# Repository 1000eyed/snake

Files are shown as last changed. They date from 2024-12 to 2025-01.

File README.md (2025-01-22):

# Snake

A semi-ortholinear keyboard with LEDs, rotary encoder support and spacebar options.

## How to build one

Very easy project.

### Part list
| # | name | comments |
|---|---|---|
| 1 | main PCB | Order at fabricator of your choice (ouch, expensive!) |
| 42 | hotswap sockets | Whatever you are into |
| 42 | switches | MX compatible |
| 42 | Keycaps | MX-compatible |
| 1 | Rotary Encoder | optional |
| NA | Rubber cord D3.53 mm |  https://www.amazon.de/-/en/SHOCRE-Rubber-Gasket-Nitrile-Diameter/dp/B0CGDMGRZM |

- Solder the sockets to the PCB according to chosen layout. 
- Mount stabilizers. Note: depending on the layout you [i]may[/i] need to file just a tad the stabilizer lips, so they clear the diodes. If they do not seem to fit, do not force them into place, inspect and file if needed!
- Mount the plate to the PCB and secure it with switches in the corners. 
- Mount all other switches.
- Cut and insert cord pieces into the pockets between the PCB and the plate.
- Insert the assembly into the case. Start with the USB side.

### Firmware

- Install WinUSB driver, using Zadig (https://github.com/qmk/qmk_firmware/blob/master/docs/driver_installation_zadig.md)
- Flash the firmware onto the board. Bootloader mode: hold top left key while plugging in. I used QMK Toolbox (https://qmk.fm/toolbox).

### Done

Enjoy your Snake!

## Acknowledgements

Joe Scotto for publishing the STM32 Scottomodule (https://www.youtube.com/joe_scotto). 
Theycallmeboxy for case inspirations (https://github.com/theycallmeboxy/bassik).

## Gallery



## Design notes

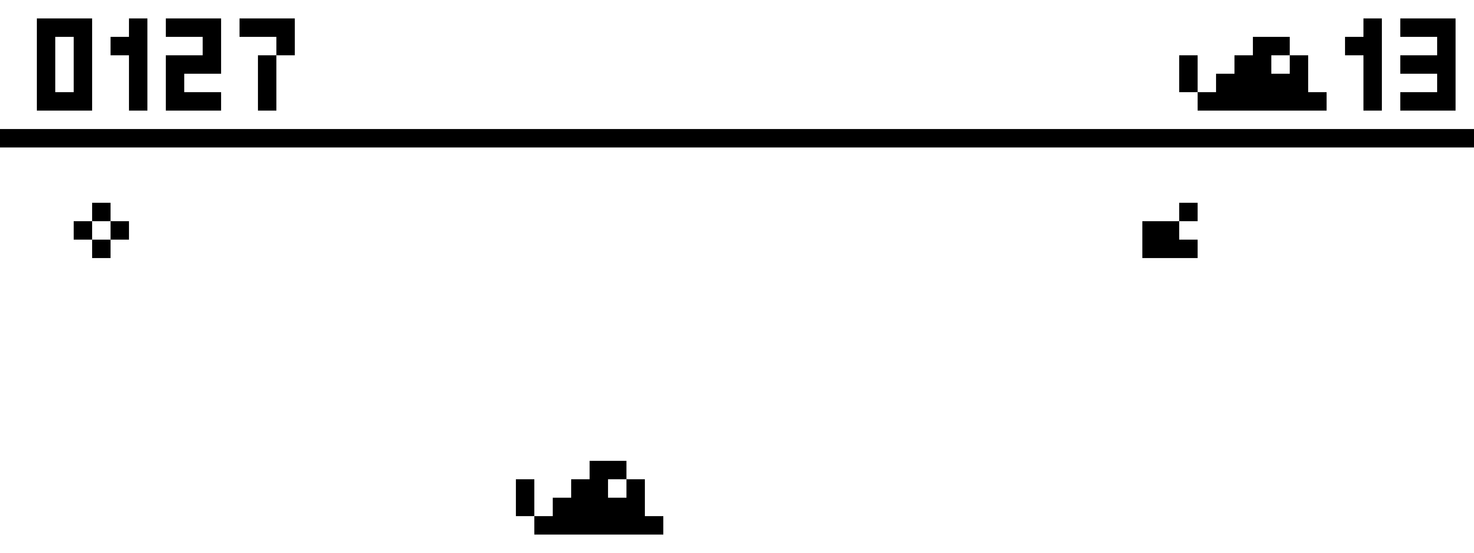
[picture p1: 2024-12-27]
snake-pcb/snake.png

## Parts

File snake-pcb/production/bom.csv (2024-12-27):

Designator | Footprint | Quantity | Value | LCSC Part #
C10, C11, C13, C16, C7, CAPLED1, CAPLED10, CAPLED11, CAPLED12, CAPLED13, CAPLED14, CAPLED15, CAPLED16, CAPLED17, CAPLED18, CAPLED19, CAPLED2, CAPLED20, CAPLED21, CAPLED22, CAPLED23, CAPLED24, CAPLED25, CAPLED26, CAPLED27, CAPLED28, CAPLED29, CAPLED3, CAPLED30, CAPLED31, CAPLED32, CAPLED33, CAPLED34, CAPLED35, CAPLED36, CAPLED37, CAPLED38, CAPLED39, CAPLED4, CAPLED40, CAPLED41, CAPLED42, CAPLED43, CAPLED5, CAPLED6, CAPLED7, CAPLED8, CAPLED9 | Capacitor_0402 | 48 | 100nF | C307331
C12, C17 | Capacitor_0402 | 2 | 4.7uF | C23733
C14 | Capacitor_0402 | 1 | 10nF | C15195
C15, C8, C9 | Capacitor_0402 | 3 | 1uF | C52923
D1, D10, D11, D12, D13, D14, D15, D16, D17, D18, D19, D2, D20, D21, D22, D23, D24, D25, D26, D27, D28, D29, D3, D30, D31, D32, D33, D34, D35, D36, D37, D38, D39, D4, D40, D41, D42, D5, D6, D7, D8, D9, DLED1 | D_SOD-123 | 43 | 1N4148W
F1 | Fuse_0603 | 1 | 500mA | C210357
J1 | USB_C_HRO_TYPE-C-31-M-12 | 1 | USB_C | C165948
J2 | JST_EH_B5B-EH-A_1x05_P2.50mm_Vertical | 1 | Conn_01x05_Socket
LED1, LED10, LED11, LED12, LED13, LED14, LED15, LED16, LED17, LED18, LED19, LED2, LED20, LED21, LED22, LED23, LED24, LED25, LED26, LED27, LED28, LED29, LED3, LED30, LED31, LED32, LED33, LED34, LED35, LED36, LED37, LED38, LED39, LED4, LED40, LED41, LED42, LED43, LED5, LED6, LED7, LED8, LED9 | LED_SK6812MINI | 43 | SK6812MINI
MX1, MX10, MX11, MX12, MX13, MX14, MX15, MX16, MX17, MX18, MX19, MX2, MX20, MX21, MX22, MX23, MX24, MX25, MX26, MX27, MX28, MX29, MX3, MX30, MX31, MX32, MX33, MX34, MX35, MX37, MX38, MX39, MX4, MX40, MX41, MX42, MX43, MX5, MX6, MX7, MX8, MX9 | SW_MX_HS_CPG151101S11_1u | 42 | MX_SW_solder
MX36 | SW_MX_HS_CPG151101S11_1.25u | 1 | MX_SW_solder
R1 | Resistor_0402 | 1 | 10k | C25744
R2, R3 | Resistor_0402 | 2 | 5.1k | C25905
S35 | STAB_MX_P_ISO-ROT | 1 | MX_stab
S39 | STAB_MX_P_2.75u | 1 | MX_stab
S40 | STAB_MX_P_2.25u | 1 | MX_stab
SW1 | Button_TL3342 | 1 | SW_Push | C115351
SW2 | Encoder_EC11_MX | 1 | RotaryEncoder_Switch
U1 | Package_LQFP-48_7x7mm_P0.5 | 1 | STM32F072CBT6 | C81720
U3 | Voltage_SOT-23 | 1 | XC6206 | C5446
U4 | ESD_SOT-23-6 | 1 | USBLC6-2SC6 | C2827654

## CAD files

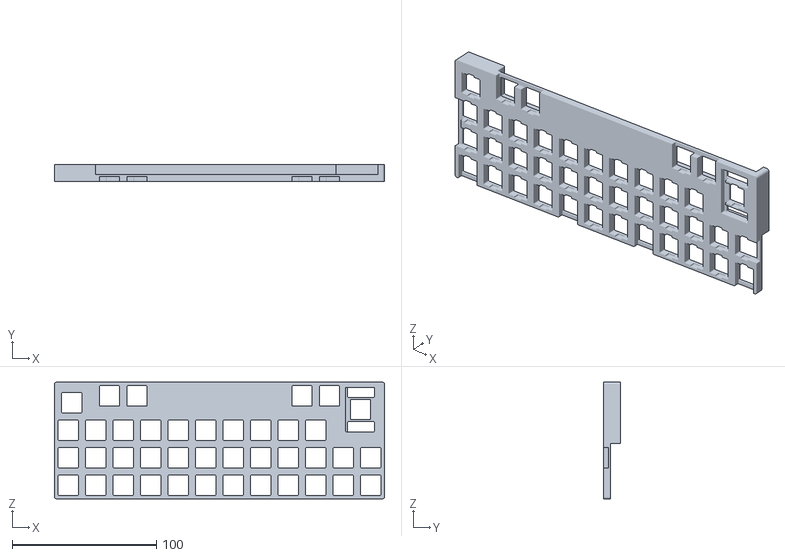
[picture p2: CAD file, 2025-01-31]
snake-case/plate, ortho+ISO+7U seesaw mount.stl
228.6 x 12.0 x 81.0

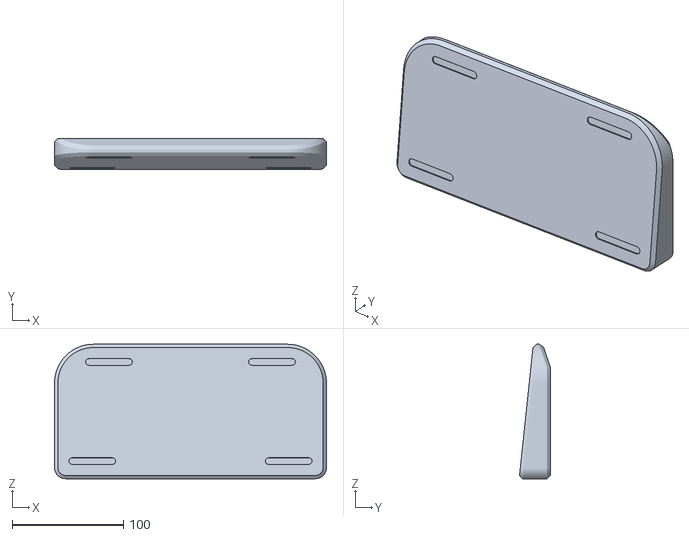
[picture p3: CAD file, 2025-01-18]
snake-case/case deeper SKUF.stl
244.6 x 27.9 x 121.0

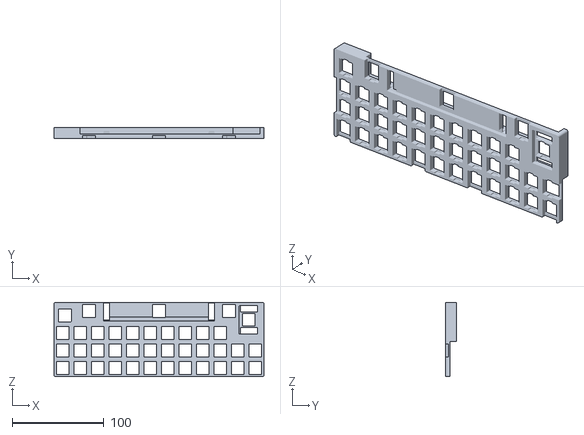
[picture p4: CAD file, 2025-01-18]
snake-case/plate, ortho+ISO+7U stabilized.stl
228.6 x 12.0 x 81.0

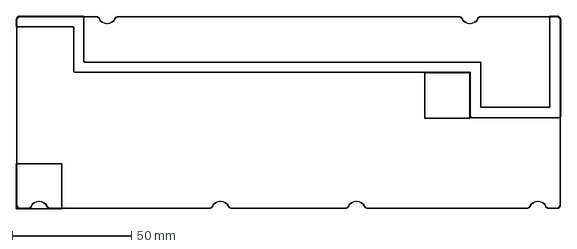
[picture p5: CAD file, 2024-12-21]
snake-case/pcb edge cuts and led position.dxf
228.6 x 81.0 mm

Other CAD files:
snake-case/snake v9.step
snake-case/case.stl
snake-case/snake.f3d

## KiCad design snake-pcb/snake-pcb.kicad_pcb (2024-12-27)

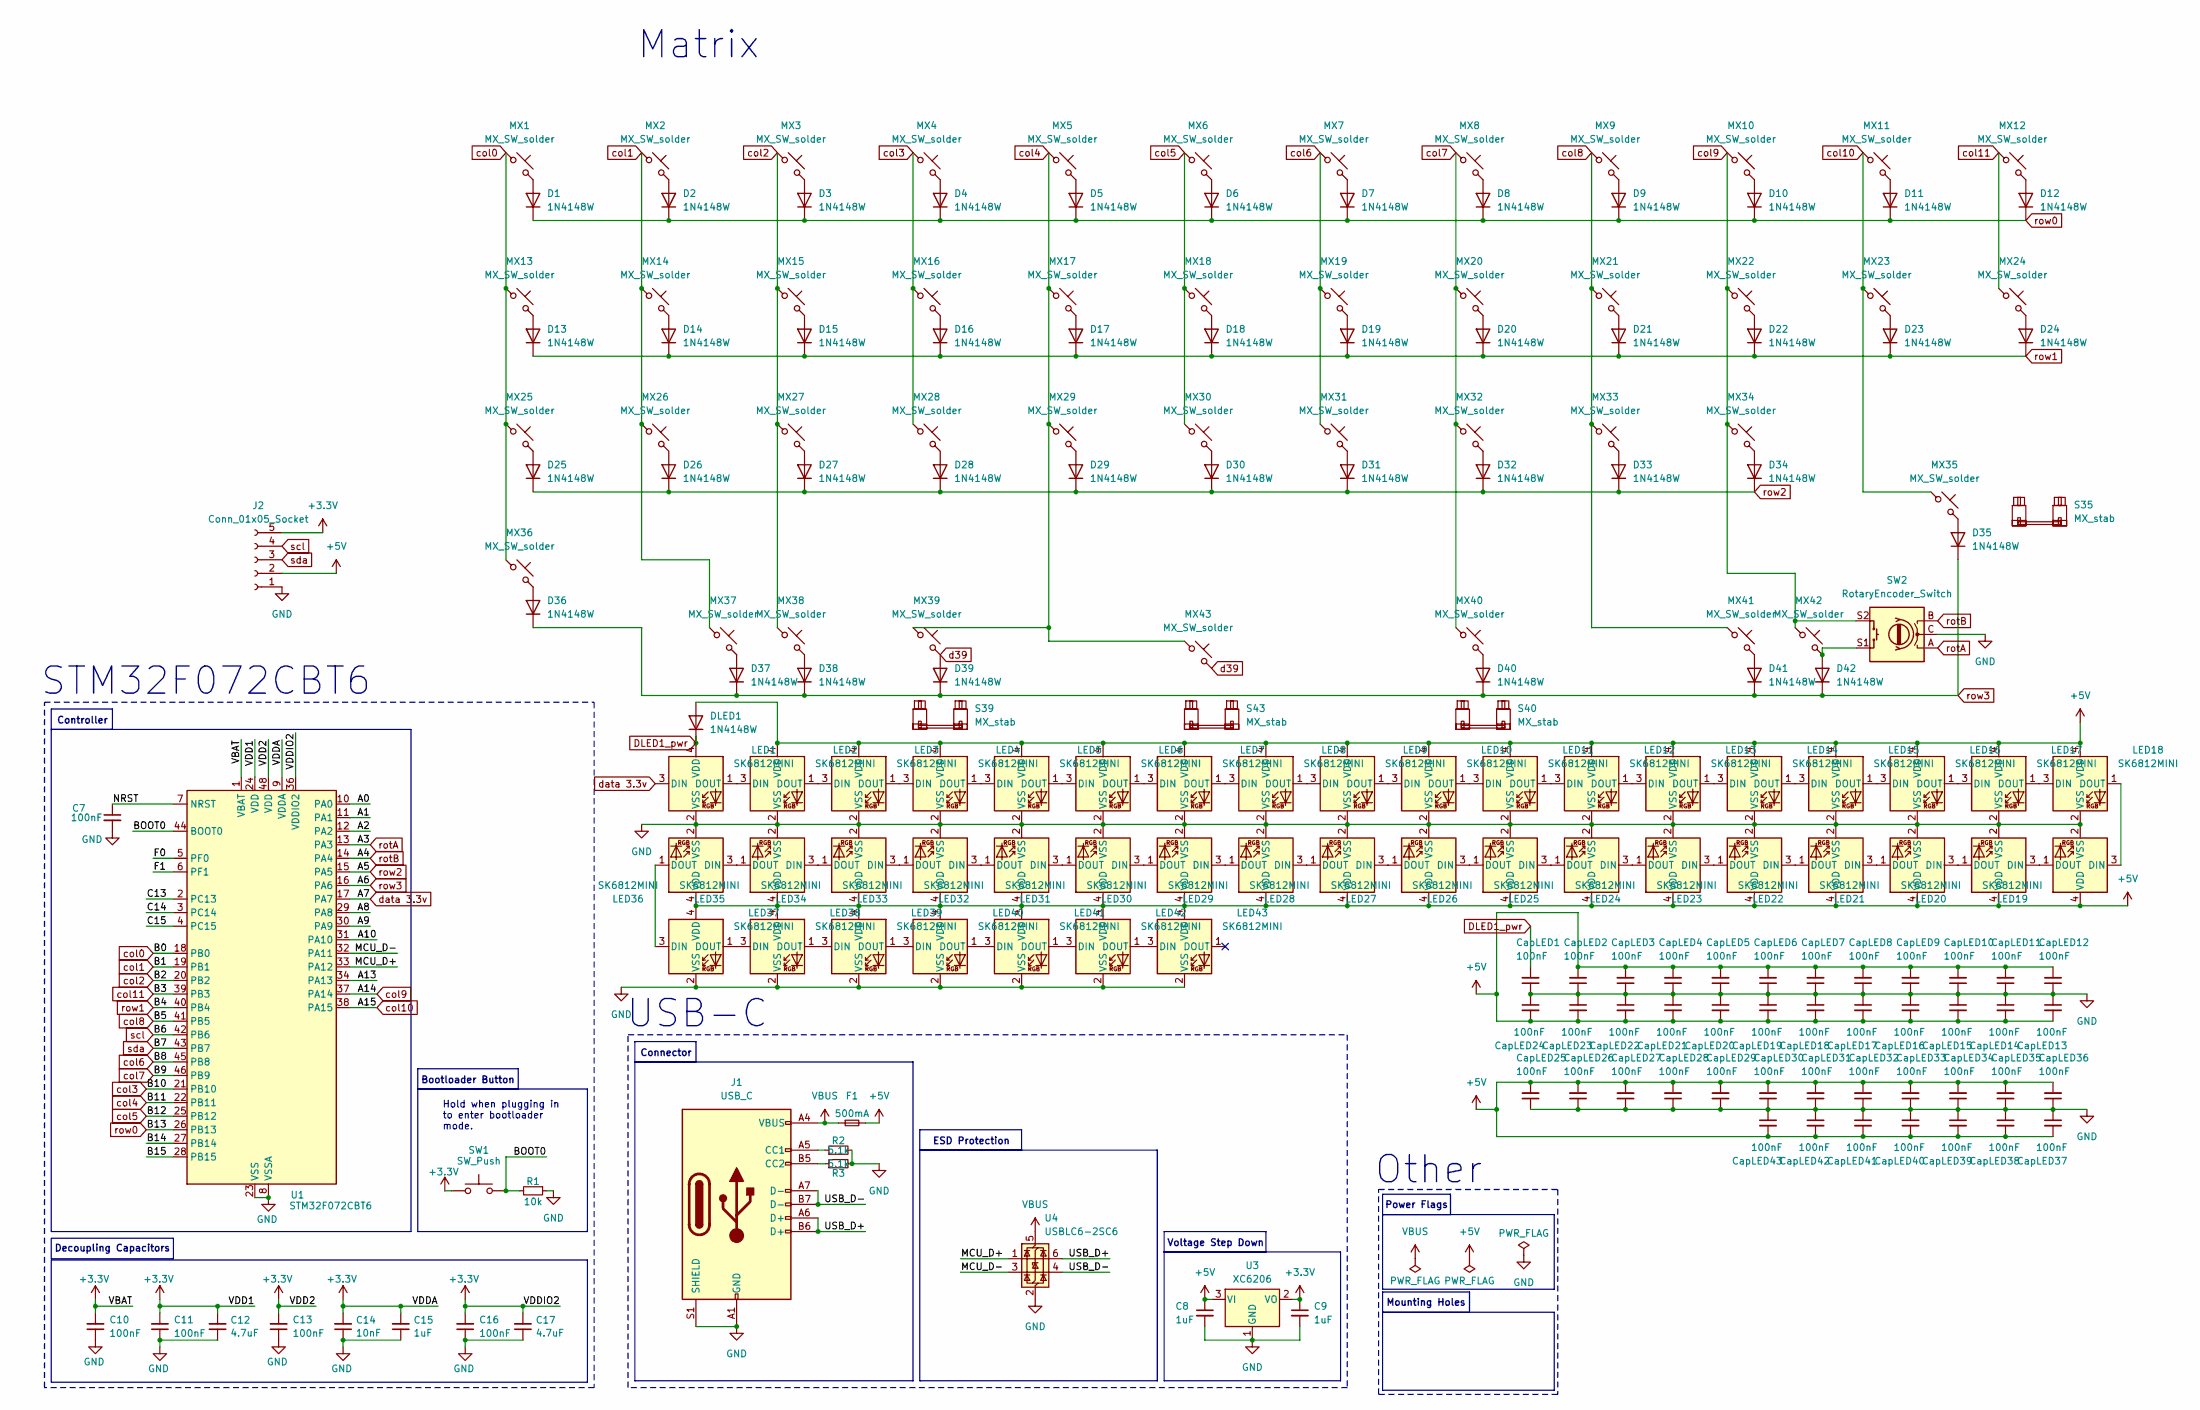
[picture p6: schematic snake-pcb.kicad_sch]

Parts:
C7: 100nF; Capacitor_0402; LCSC C307331
C8, C9: 1uF; Capacitor_0402; LCSC C52923
C10, C11, C13, C16: 100nF; Capacitor_0402; MPN CL05B104KB54PNC; LCSC C307331
C12, C17: 4.7uF; Capacitor_0402; MPN CL05A475MP5NRNC; LCSC C23733
C14: 10nF; Capacitor_0402; MPN CL05B103KB5NNNC; LCSC C15195
C15: 1uF; Capacitor_0402; MPN CL05A105KA5NQNC; LCSC C52923
CapLED1, CapLED2, CapLED3, CapLED4, CapLED5, CapLED6, CapLED7, CapLED8, CapLED9, CapLED10, CapLED11, CapLED12, CapLED13, CapLED14, CapLED15, CapLED16, CapLED17, CapLED18, CapLED19, CapLED20, CapLED21, CapLED22, CapLED23, CapLED24, CapLED25, CapLED26, CapLED27, CapLED28, CapLED29, CapLED30, CapLED31, CapLED32, CapLED33, CapLED34, CapLED35, CapLED36, CapLED37, CapLED38, CapLED39, CapLED40, CapLED41, CapLED42, CapLED43: 100nF; Capacitor_0402; MPN CL05B104KB54PNC; LCSC C307331
D1, D2, D3, D4, D5, D6, D7, D8, D9, D10, D11, D12, D13, D14, D15, D16, D17, D18, D19, D20, D21, D22, D23, D24, D25, D26, D27, D28, D29, D30, D31, D32, D33, D34, D35, D36, D37, D38, D39, D40, D41, D42: 1N4148W; D_SOD-123
DLED1: 1N4148W; D_SOD-123
F1: 500mA; Fuse_0603; LCSC C210357
J1: USB_C; USB_C_HRO_TYPE-C-31-M-12; LCSC C165948
J2: Conn_01x05_Socket; JST_EH_B5B-EH-A_1x05_P2.50mm_Vertical
LED1, LED2, LED3, LED4, LED5, LED6, LED7, LED8, LED9, LED10, LED11, LED12, LED13, LED14, LED15, LED16, LED17, LED18, LED19, LED20, LED21, LED22, LED23, LED24, LED25, LED26, LED27, LED28, LED29, LED30, LED31, LED32, LED33, LED34, LED35, LED36, LED37, LED38, LED39, LED40, LED41, LED42, LED43: SK6812MINI; LED_SK6812MINI
MX1, MX2, MX3, MX4, MX5, MX6, MX7, MX8, MX9, MX10, MX11, MX12, MX13, MX14, MX15, MX16, MX17, MX18, MX19, MX20, MX21, MX22, MX23, MX24, MX25, MX26, MX27, MX28, MX29, MX30, MX31, MX32, MX33, MX34, MX35, MX37, MX38, MX39, MX40, MX41, MX42, MX43: MX_SW_solder; SW_MX_HS_CPG151101S11_1u
MX36: MX_SW_solder; SW_MX_HS_CPG151101S11_1.25u
R1: 10k; Resistor_0402; LCSC C25744
R2, R3: 5.1k; Resistor_0402; LCSC C25905
S35: MX_stab; STAB_MX_P_ISO-ROT
S39: MX_stab; STAB_MX_P_2.75u
S40: MX_stab; STAB_MX_P_2.25u
S43: MX_stab; STAB_MX_P_7u
SW1: SW_Push; Button_TL3342; LCSC C115351
SW2: RotaryEncoder_Switch; Encoder_EC11_MX
U1: STM32F072CBT6; Package_LQFP-48_7x7mm_P0.5; LCSC C81720
U3: XC6206; Voltage_SOT-23; LCSC C5446
U4: USBLC6-2SC6; ESD_SOT-23-6; LCSC C2827654

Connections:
+3.3V: C9.1, C10.2, C11.2, C12.2, C13.2, C14.2, C15.2, C16.2, C17.2, J2.5, SW1.1, U1.1 (VBAT), U1.9 (VDDA), U1.24 (VDD), U1.36 (VDDIO2), U1.48 (VDD), U3.2 (VO)
+5V: C8.1, CapLED2.2, CapLED3.2, CapLED4.2, CapLED5.2, CapLED6.2, CapLED7.2, CapLED8.2, CapLED9.2, CapLED10.2, CapLED11.2, CapLED12.2, CapLED13.2, CapLED14.2, CapLED15.2, CapLED16.2, CapLED17.2, CapLED18.2, CapLED19.2, CapLED20.2, CapLED21.2, CapLED22.2, CapLED23.2, CapLED24.2, CapLED25.2, CapLED26.2, CapLED27.2, CapLED28.2, CapLED29.2, CapLED30.2, CapLED31.2, CapLED32.2, CapLED33.2, CapLED34.2, CapLED35.2, CapLED36.2, CapLED37.2, CapLED38.2, CapLED39.2, CapLED40.2, CapLED41.2, CapLED42.2, CapLED43.2, DLED1.2 (A), F1.2, J2.2, LED2.4 (VDD), LED3.4 (VDD), LED4.4 (VDD), LED5.4 (VDD), LED6.4 (VDD), LED7.4 (VDD), LED8.4 (VDD), LED9.4 (VDD), LED10.4 (VDD), LED11.4 (VDD), LED12.4 (VDD), LED13.4 (VDD), LED14.4 (VDD), LED15.4 (VDD), LED16.4 (VDD), LED17.4 (VDD), LED18.4 (VDD), LED19.4 (VDD), LED20.4 (VDD), LED21.4 (VDD), LED22.4 (VDD), LED23.4 (VDD), LED24.4 (VDD), LED25.4 (VDD), LED26.4 (VDD), LED27.4 (VDD), LED28.4 (VDD), LED29.4 (VDD), LED30.4 (VDD), LED31.4 (VDD), LED32.4 (VDD), LED33.4 (VDD), LED34.4 (VDD), LED35.4 (VDD), LED36.4 (VDD), LED37.4 (VDD), LED38.4 (VDD), LED39.4 (VDD), LED40.4 (VDD), LED41.4 (VDD), LED42.4 (VDD), LED43.4 (VDD), U3.3 (VI)
/A0: U1.10 (PA0)
/A1: U1.11 (PA1)
/A2: U1.12 (PA2)
/A8: U1.29 (PA8)
/A9: U1.30 (PA9)
/A10: U1.31 (PA10)
/A13: U1.34 (PA13)
/B14: U1.27 (PB14)
/B15: U1.28 (PB15)
/BOOT0: R1.2, SW1.2, U1.44 (BOOT0)
/C13: U1.2 (PC13)
/C14: U1.3 (PC14)
/C15: U1.4 (PC15)
/F0: U1.5 (PF0)
/F1: U1.6 (PF1)
/MCU_D+: U1.33 (PA12), U4.1 (I/O1)
/MCU_D-: U1.32 (PA11), U4.3 (I/O2)
/NRST: C7.1, U1.7 (NRST)
/USB_D+: J1.A6 (D+), J1.B6 (D+), U4.6 (I/O1)
/USB_D-: J1.A7 (D-), J1.B7 (D-), U4.4 (I/O2)
DLED1_pwr: CapLED1.2, DLED1.1 (K), LED1.4 (VDD)
GND: C7.2, C8.2, C9.2, C10.1, C11.1, C12.1, C13.1, C14.1, C15.1, C16.1, C17.1, CapLED1.1, CapLED2.1, CapLED3.1, CapLED4.1, CapLED5.1, CapLED6.1, CapLED7.1, CapLED8.1, CapLED9.1, CapLED10.1, CapLED11.1, CapLED12.1, CapLED13.1, CapLED14.1, CapLED15.1, CapLED16.1, CapLED17.1, CapLED18.1, CapLED19.1, CapLED20.1, CapLED21.1, CapLED22.1, CapLED23.1, CapLED24.1, CapLED25.1, CapLED26.1, CapLED27.1, CapLED28.1, CapLED29.1, CapLED30.1, CapLED31.1, CapLED32.1, CapLED33.1, CapLED34.1, CapLED35.1, CapLED36.1, CapLED37.1, CapLED38.1, CapLED39.1, CapLED40.1, CapLED41.1, CapLED42.1, CapLED43.1, J1.A1 (GND), J1.A12 (GND), J1.B1 (GND), J1.B12 (GND), J1.S1 (SHIELD), J2.1, LED1.2 (VSS), LED2.2 (VSS), LED3.2 (VSS), LED4.2 (VSS), LED5.2 (VSS), LED6.2 (VSS), LED7.2 (VSS), LED8.2 (VSS), LED9.2 (VSS), LED10.2 (VSS), LED11.2 (VSS), LED12.2 (VSS), LED13.2 (VSS), LED14.2 (VSS), LED15.2 (VSS), LED16.2 (VSS), LED17.2 (VSS), LED18.2 (VSS), LED19.2 (VSS), LED20.2 (VSS), LED21.2 (VSS), LED22.2 (VSS), LED23.2 (VSS), LED24.2 (VSS), LED25.2 (VSS), LED26.2 (VSS), LED27.2 (VSS), LED28.2 (VSS), LED29.2 (VSS), LED30.2 (VSS), LED31.2 (VSS), LED32.2 (VSS), LED33.2 (VSS), LED34.2 (VSS), LED35.2 (VSS), LED36.2 (VSS), LED37.2 (VSS), LED38.2 (VSS), LED39.2 (VSS), LED40.2 (VSS), LED41.2 (VSS), LED42.2 (VSS), LED43.2 (VSS), R1.1, R2.2, R3.2, SW2.C, U1.8 (VSSA), U1.23 (VSS), U1.35 (VSS), U1.47 (VSS), U3.1 (GND), U4.2 (GND)
unnamed: D1.2 (A), MX1.2
unnamed: D2.2 (A), MX2.2
unnamed: D3.2 (A), MX3.2
unnamed: D4.2 (A), MX4.2
unnamed: D5.2 (A), MX5.2
unnamed: D6.2 (A), MX6.2
unnamed: D7.2 (A), MX7.2
unnamed: D8.2 (A), MX8.2
unnamed: D9.2 (A), MX9.2
unnamed: D10.2 (A), MX10.2
unnamed: D11.2 (A), MX11.2
unnamed: D12.2 (A), MX12.2
unnamed: D13.2 (A), MX13.2
unnamed: D14.2 (A), MX14.2
unnamed: D15.2 (A), MX15.2
unnamed: D16.2 (A), MX16.2
unnamed: D17.2 (A), MX17.2
unnamed: D18.2 (A), MX18.2
unnamed: D19.2 (A), MX19.2
unnamed: D20.2 (A), MX20.2
unnamed: D21.2 (A), MX21.2
unnamed: D22.2 (A), MX22.2
unnamed: D23.2 (A), MX23.2
unnamed: D24.2 (A), MX24.2
unnamed: D25.2 (A), MX25.2
unnamed: D26.2 (A), MX26.2
unnamed: D27.2 (A), MX27.2
unnamed: D28.2 (A), MX28.2
unnamed: D29.2 (A), MX29.2
unnamed: D30.2 (A), MX30.2
unnamed: D31.2 (A), MX31.2
unnamed: D32.2 (A), MX32.2
unnamed: D33.2 (A), MX33.2
unnamed: D34.2 (A), MX34.2
unnamed: D35.2 (A), MX35.2
unnamed: D36.2 (A), MX36.2
unnamed: D37.2 (A), MX37.2
unnamed: D38.2 (A), MX38.2
unnamed: D40.2 (A), MX40.2
unnamed: D41.2 (A), MX41.2
unnamed: D42.2 (A), MX42.2, SW2.S1
unnamed: J1.A5 (CC1), R2.1
unnamed: J1.B5 (CC2), R3.1
unnamed: LED1.1 (DOUT), LED2.3 (DIN)
unnamed: LED2.1 (DOUT), LED3.3 (DIN)
unnamed: LED3.1 (DOUT), LED4.3 (DIN)
unnamed: LED4.1 (DOUT), LED5.3 (DIN)
unnamed: LED5.1 (DOUT), LED6.3 (DIN)
unnamed: LED6.1 (DOUT), LED7.3 (DIN)
unnamed: LED7.1 (DOUT), LED8.3 (DIN)
unnamed: LED8.1 (DOUT), LED9.3 (DIN)
unnamed: LED9.1 (DOUT), LED10.3 (DIN)
unnamed: LED10.1 (DOUT), LED11.3 (DIN)
unnamed: LED11.1 (DOUT), LED12.3 (DIN)
unnamed: LED12.1 (DOUT), LED13.3 (DIN)
unnamed: LED13.1 (DOUT), LED14.3 (DIN)
unnamed: LED14.1 (DOUT), LED15.3 (DIN)
unnamed: LED15.1 (DOUT), LED16.3 (DIN)
unnamed: LED16.1 (DOUT), LED17.3 (DIN)
unnamed: LED17.1 (DOUT), LED18.3 (DIN)
unnamed: LED18.1 (DOUT), LED19.3 (DIN)
unnamed: LED19.1 (DOUT), LED20.3 (DIN)
unnamed: LED20.1 (DOUT), LED21.3 (DIN)
unnamed: LED21.1 (DOUT), LED22.3 (DIN)
unnamed: LED22.1 (DOUT), LED23.3 (DIN)
unnamed: LED23.1 (DOUT), LED24.3 (DIN)
unnamed: LED24.1 (DOUT), LED25.3 (DIN)
unnamed: LED25.1 (DOUT), LED26.3 (DIN)
unnamed: LED26.1 (DOUT), LED27.3 (DIN)
unnamed: LED27.1 (DOUT), LED28.3 (DIN)
unnamed: LED28.1 (DOUT), LED29.3 (DIN)
unnamed: LED29.1 (DOUT), LED30.3 (DIN)
unnamed: LED30.1 (DOUT), LED31.3 (DIN)
unnamed: LED31.1 (DOUT), LED32.3 (DIN)
unnamed: LED32.1 (DOUT), LED33.3 (DIN)
unnamed: LED33.1 (DOUT), LED34.3 (DIN)
unnamed: LED34.1 (DOUT), LED35.3 (DIN)
unnamed: LED35.1 (DOUT), LED36.3 (DIN)
unnamed: LED36.1 (DOUT), LED37.3 (DIN)
unnamed: LED37.1 (DOUT), LED38.3 (DIN)
unnamed: LED38.1 (DOUT), LED39.3 (DIN)
unnamed: LED39.1 (DOUT), LED40.3 (DIN)
unnamed: LED40.1 (DOUT), LED41.3 (DIN)
unnamed: LED41.1 (DOUT), LED42.3 (DIN)
unnamed: LED42.1 (DOUT), LED43.3 (DIN)
VBUS: F1.1, J1.A4 (VBUS), J1.A9 (VBUS), J1.B4 (VBUS), J1.B9 (VBUS), U4.5 (VBUS)
col0: MX1.1, MX13.1, MX25.1, MX36.1, U1.18 (PB0)
col1: MX2.1, MX14.1, MX26.1, MX37.1, U1.19 (PB1)
col2: MX3.1, MX15.1, MX27.1, MX38.1, U1.20 (PB2)
col3: MX4.1, MX16.1, MX28.1, U1.21 (PB10)
col4: MX5.1, MX17.1, MX29.1, MX39.1, MX43.1, U1.22 (PB11)
col5: MX6.1, MX18.1, MX30.1, U1.25 (PB12)
col6: MX7.1, MX19.1, MX31.1, U1.45 (PB8)
col7: MX8.1, MX20.1, MX32.1, MX40.1, U1.46 (PB9)
col8: MX9.1, MX21.1, MX33.1, MX41.1, U1.41 (PB5)
col9: MX10.1, MX22.1, MX34.1, MX42.1, SW2.S2, U1.37 (PA14)
col10: MX11.1, MX23.1, MX35.1, U1.38 (PA15)
col11: MX12.1, MX24.1, U1.39 (PB3)
d39: D39.2 (A), MX39.2, MX43.2
data 3.3v: LED1.3 (DIN), U1.17 (PA7)
rotA: SW2.A, U1.13 (PA3)
rotB: SW2.B, U1.14 (PA4)
row0: D1.1 (K), D2.1 (K), D3.1 (K), D4.1 (K), D5.1 (K), D6.1 (K), D7.1 (K), D8.1 (K), D9.1 (K), D10.1 (K), D11.1 (K), D12.1 (K), U1.26 (PB13)
row1: D13.1 (K), D14.1 (K), D15.1 (K), D16.1 (K), D17.1 (K), D18.1 (K), D19.1 (K), D20.1 (K), D21.1 (K), D22.1 (K), D23.1 (K), D24.1 (K), U1.40 (PB4)
row2: D25.1 (K), D26.1 (K), D27.1 (K), D28.1 (K), D29.1 (K), D30.1 (K), D31.1 (K), D32.1 (K), D33.1 (K), D34.1 (K), U1.15 (PA5)
row3: D35.1 (K), D36.1 (K), D37.1 (K), D38.1 (K), D39.1 (K), D40.1 (K), D41.1 (K), D42.1 (K), U1.16 (PA6)
scl: J2.4, U1.42 (PB6)
sda: J2.3, U1.43 (PB7)

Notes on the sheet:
Hold when plugging in to enter bootloader mode.
STM32F072CBT6
USB-C
Mounting Holes
Decoupling Capacitors
Controller
ESD Protection
Power Flags
Voltage Step Down
Other
Bootloader Button
Matrix
Connector

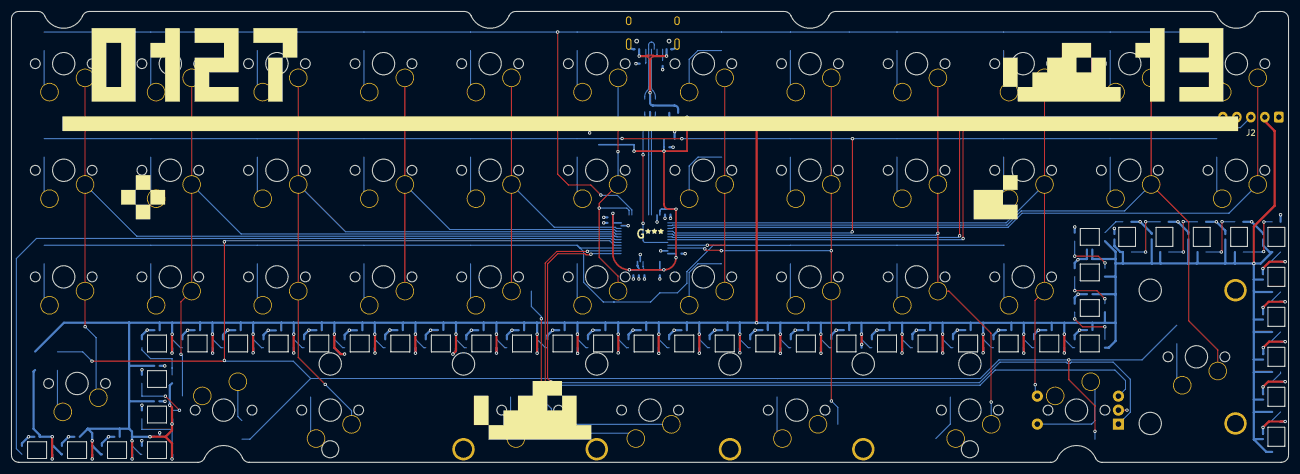
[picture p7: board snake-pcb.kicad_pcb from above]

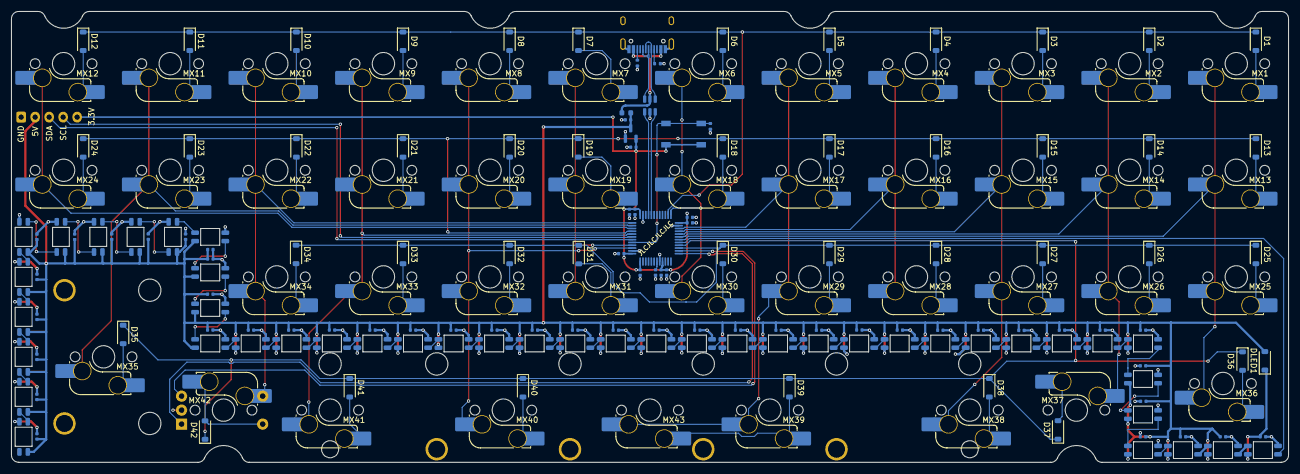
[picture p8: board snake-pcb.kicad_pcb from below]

Board: 4 copper layers, 228.2 x 80.6 mm, 198 parts (192 on the bottom side), 118 nets.

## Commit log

2024-12-27 pcb almost finished!
    [bom.csv, designators.csv, positions.csv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]
2024-12-27 pcb almost ever mo finished!
    [snake-pcb.kicad_pcb]
2024-12-27 gerbers added
    [bom.csv, designators.csv]
2024-12-27 pcb done
    [snake-pcb.kicad_pcb]
2025-01-18 Files ready
    [case deeper SKUF.stl, plate, ortho+ISO+7U space stabilizer incorrect.stl, plate, ortho+ISO+7U.stl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]
2025-01-31 plate changes: added seesaw mount plate, removed faulty plate version STL, 3df file updated.
    [plate, ortho+ISO+7U seesaw mount.stl, plate, ortho+ISO+7U stabilized.stl, plate, ortho+ISO+7U.stl]
2025-01-31 faulty plate removed now
    [plate, ortho+ISO+7U space stabilizer incorrect.stl]
